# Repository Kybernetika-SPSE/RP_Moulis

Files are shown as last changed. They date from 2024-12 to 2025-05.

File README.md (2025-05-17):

# Modernizace zvukového systému

## 📌 O projektu  
Tento projekt se zaměřuje na modernizaci starého zvukového systému.

## 🛠 Použité technologie  
- **Raspberry Pi Zero 2 W** – hlavní řídicí jednotka  
- **Spotify API** – integrace pro ovládání přehrávání hudby  
- **Raspotify** – umožňuje zařízení fungovat jako Spotify Connect zařízení  
- **Bluetooth Audio** – pro přímé připojení mobilního telefonu  
- **Pulseaudio** – správa zvuku  
- **Spotipy** – Python knihovna pro práci se Spotify  

## ✨ Funkce  
- Přehrávání hudby ze Spotify přes Spotify Connect  
- Možnost připojení přes Bluetooth jako externí reproduktor  
- Zobrazení informací o aktuálně přehrávané skladbě na displeji  
- Více možností zvukového výstupu (3.5 mm Jack, Cinch)  

## 📢 Instalace  
1. **PRaspberry Pi Zero 2 W** s operačním systémem Raspberry Pi OS Lite.  
2. **Potřebné balíčky**:
   ```bash
   sudo apt update && sudo apt install -y curl git python3-pip pulseaudio bluez-tools

- Konfigurace zvukového výstupu: Do souboru /boot/config.txt se přidají následující řádky:
   ```
   dtparam=audio=on
   gpio=12,13,a5
   audio_pwm_mode=2
   dtoverlay=audremap, pins_12_13

- Instalace Raspotify pro přehrávání Spotify:
   ```
   curl -sL https://dtcooper.github.io/raspotify/install.sh | bash

- Konfigurace Bluetooth pro automatické párování:
   ```
   sudo systemctl enable bluetooth
   sudo systemctl start bluetooth

## 🔧 Možná vylepšení
- Integrace baterie pro plně přenosné využití
- Vylepšení grafického rozhraní na displeji
- Snížení šumu na zvukovém výstupu

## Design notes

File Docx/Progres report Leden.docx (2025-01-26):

# Progres report

Leden 2025

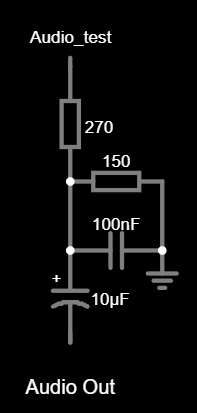
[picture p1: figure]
Obsah obrázku text, snímek obrazovky, Písmo, diagram Popis byl vytvořen automaticky

Moulis Vít

# Audio

Relativně bez problému jsem nastavil audio výstup přes PWM.

Taky jsem na desku nahrál testovací mp3 soubor. V předinstalovaném programu (VLC) jsem ho úspěšně spustil.

Všiml jsem si, že ve výstupu je slyšet šum internetové komunikace, jako připojení internetu přes pevnou linku. Když Raspberry stahuje data nebo mám připojený program na vzdálené ovládání, je to výrazně slyšet, ale při přehrávání není šum rušivý.

Přikládám schéma obvodu. Pro oba kanály jsem udělal jeden takový filtr, aby pomohl vyhladit ostrý zvuk PWM audia.

# RFID

Obrázek 1: Schéma audio filtru

Používám čtečku s čipem RC522 a komunikační frekvencí 13.56 Mhz.

Pro RFID čtečku jsem nainstaloval knihovnu mfrc522 a postupně vyzkoušel několik example kódů. U všech jsem narazil na to, že mi čtečka neregistruje čip. Navíc všechny knihovny jsou buď zastaralé nebo pro Arduino. Zvažuji o použití jiné čtečky RFID, která umožňuje jiný komunikační standard než UART.

# Spotify

Na desku jsem nainstaloval následující knihovny a software:

- Librespot – Knihovna pro imitaci funkcí Spotify Connect
- Raspotify – Rozšírení Librespot pro Raspberry Pi
- Spotipy – Knihovna pro komunikaci se Spotify API přes Python
- Webový prohlížeč Puffin

Narazil jsem na problém s Raspotify, kdy program spadl pokaždé, když jsem se pokusil přenést playback na Raspberry, někdy dokonce spadl celý OS. Musel jsem v configu knihovny Librespot změnit výchozí zařízení pro výstup zvuku, aby fungoval s mým audio výstupem, což probém vyřešilo.

Další krok bude autorizace API, aby deska mohla odesílat příkazy na přehrávání. V tom jsem zatím neuspěl. Mám udělanou aplikaci na stránkách Spotify a snažím se získat autorizaci pro zařízení. Nastavil jsem systémové proměnné s přihlašovacími údaji a stáhl light-weight prohlížeč, který dokáže otevírat webovky graficky.

Program z pythonu vezme přihlašovací údaje a udělá request na autorizaci. Ten se po přihlášení přesměruje na jinou adresu, v mém případě localhost:8080. U přesměrované adresy mi vyskočí error-conection_refused. Všechno tohle zpracovává knihovna Spotipy, co jsem se zjistil z dokumentace a návodu na nastavení tak by si knihovna měla vzít data z přesměrované adresy, což se neděje. Nezáleží na tom, jestli autorizuji přes uživatelské jméno a heslo přímo na raspberry nebo url překopíruju na počítač, tam se přihlásím a vrátím přesměrovanou adresu zpět, výsledek je stejný.

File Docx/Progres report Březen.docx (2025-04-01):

# Progres report

Únor 2025

Moulis Vít

# Hardware

Rozhodl jsem se přidat napájení na usb-C, bohužel jsem byl obehrán breakoutem z Číny a ten poslal 9V přímo do desky. Objednal jsem nové Raspberry Zero a začal jsem resuscitovat sd kartu, ve které se poškodily data. Podařilo se mi zařízení opravit, ale integrace Raspotify nyní nefunguje tak spolehlivě jako předtím, zatím se mi nepodařilo zjistit jestli to je updatem Spotify nebo novou deskou.

Rovněž jsem předělal DAC převodník, který zprostředkovává audio výstup, jelikož pouštěl hodně šumu. Problém jsem nakonec vystopoval na špatně připájené uzemnění cinchů.

# Software

Ze softwarové stránky zařízení funguje, občas se display zasekne nebo přestane fungovat a je potřeba restartovat python skript. Kvůli nutnosti wifi připojení a momentální nespolehlivosti Raspotify knihovny jsem přidal Bluetooth. Zařízení je tak možné používat i offline jako BT reproduktor.

Do python skriptu, který řeší Spotify API požadavky a výstup na display jsem přidal BT mód, kdy zařízení vypisuje:

{logo Bluetooth} Bluetooth

{Jméno aktivního BT zařízení}

# Krabička

Dokončil jsem krabičku pro zařízení, je mnohem robustnější než starý design.

# Implementace

Mírně jsem upravil rozhraní, aby lépe sedělo k reproduktorové věži a zároveň bylo uživatelsky použitelné.

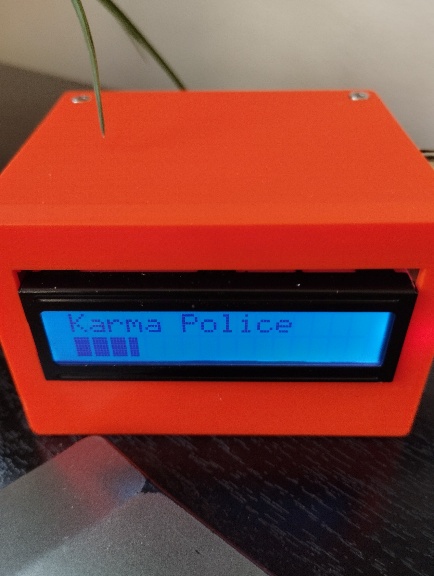
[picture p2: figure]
Obsah obrázku interiér Obsah vygenerovaný umělou inteligencí může být nesprávný.
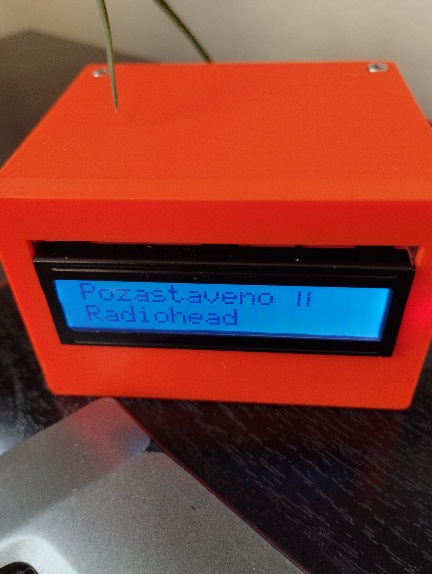
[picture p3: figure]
Obsah obrázku elektronika, interiér Obsah vygenerovaný umělou inteligencí může být nesprávný.
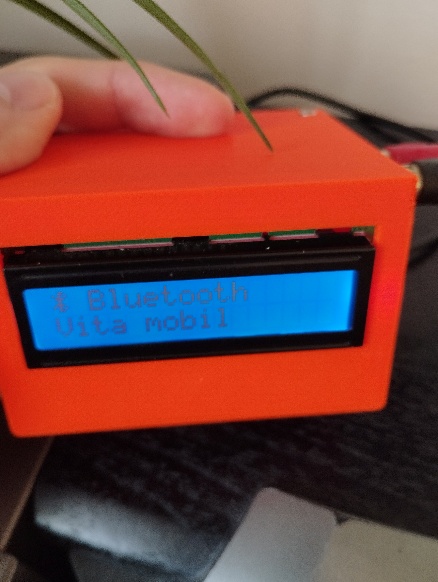
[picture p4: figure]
Obsah obrázku interiér, elektronika Obsah vygenerovaný umělou inteligencí může být nesprávný.

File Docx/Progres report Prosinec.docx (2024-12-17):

# Progress report k 20.12.2024

Prošel jsem internet pro inspiraci. Našel jsem několik podobných projektů a vyvodil jsem, že nejlepší deska pro mě bude Raspberry Pi Zero. Až deska dorazí, dalším krokem bude seznámit se s fungovaním raspberry a také budu muset sestrojit shield na audio výstup + nějaký UI.

O dalším postupu se rozhodnu, až zjistím co je reálně možné s deskou dělat. Podle toho buď přidám display, nebo se ponořím do implementace RFID čtečky. S ní by se dal imitovat vzhled walkmana s kazetkami s RFID čipem, které by při naskenování spustili určitou skladbu nebo album ze Spotify.

Zatím jsem nikde nenašel, že by nějak šlo stahovat skladby ze Spotify kvůli jejich ochraně proti pirátství. Takže nejspíš bude zařízení fungovat pouze s připojením k internetu. Tím pádem docela odpadá smysl dělat zařízení kapesní/přenosné. Zatím nebudu měnit cíl mé práce, rozhodnu se až si vyzkouším, co je možné s deskou dělat.

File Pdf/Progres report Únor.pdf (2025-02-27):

# Progresreport

Únor 2025

Moulis Vít

## Hardware

Mírně jsem přehodnotil, co od zařízení očekávám, zčásti kvůli technickým limitacím.

RFID čtečku, kterou jsem chtěl do zařízení zahrnout, jsem se rozhodl vyřadit. Nepodařilo se mi najít, jak čtečku rozběhnout s Raspberry Pi. Knihovny pro mojí RFID čtečku (mfrc522) buď nejsou pro python nebo nepodporující UART, a jiný standart moje čtečka nepodporuje.

Přidal jsem k zařízení displej, a to LCD1602 s I2C shieldem, který se k životu probral až podezřele snadno. Na display vypisuji informace o playbacku.

STATUS
ZAŘÍZENÍ

NEPŘIPOJENÝ
ÚČET

PŘI PŘIPOJENÍ HUDBA SE
PŘEHRÁVÁ

HUDBA JE
POZASTAVENA
ZPRÁVA NA
PRVNÍM ŘÁDKU
Chyba pri init | Prihlasen jako: | {Název skladby} | Pozastaveno *

ZPRÁVA NA
DRUHÉM ŘÁDKU
Pripojte ucet | {Přihlášený uživatel} | {Interpret} | {Přihlášený uživatel}

*Zde se tiskne vlastní znak, takový ty dvě čárky.

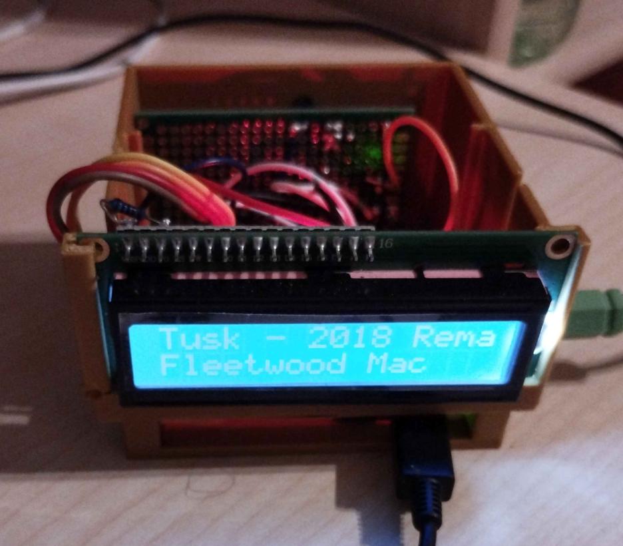
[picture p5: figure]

## Software

Podařilo se mi provést autorizaci zařízení. Knihovna spotipy, přes kterou ovládám spotify playback, má funkci, která automaticky řeší autorizaci tokenů. Pokud to v paměti najde token, tak se autorizuje, pokud ne, pošle web request a získá autorizační kód, se kterým už si poradí. Tento request je potřeba provést pouze jednou, ale právě tady byl problém. Pi Zero 2 W nemá dost RAM na spuštění prohlížeče. Nakonec jsem dokázal obejít prohlížeč tak, že jsem do VS Code nainstaloval rozšíření pro SSH a přes to jsem spustil můj kód v pythonu. Prohlížeč se mi otevřel v počítači a výsledný token se úspěšně vrátil do zařízení.

Zaměřil jsem se na kód v pythonu. Když se spustí, provede se autorizace a pak kód spadne do smyčky, kde dělá API požadavky a bere si údaje o přehrávání. Musel jsem zahrnout i nějaký error handeling, protože pokud není připojen účet, kód má velkou chuť crashovat.

Automatické spuštění přes Crontab. S mírnými obtížemi jsem přidal shell script, který při bootu spustí program. Navíc se každou hodinu provede git pull a jednou denně se zkusí updatovat balíčky.

## Krabička

Udělal jsem pro zařízení krabičku. Zatím jenom prototyp, aby to drželo pohromadě, pořádnou krabičku chci dělat až v březnu.

## Implementace

Mám doma starou Hi-Fi věž, kterou roky nikdo nepoužíval, protože se do ní špatně pouští hudba. Udělal jsem si jack-cinch adaptér a připojil k ní zařízení, a tím jsem tak věži dal druhou šanci.

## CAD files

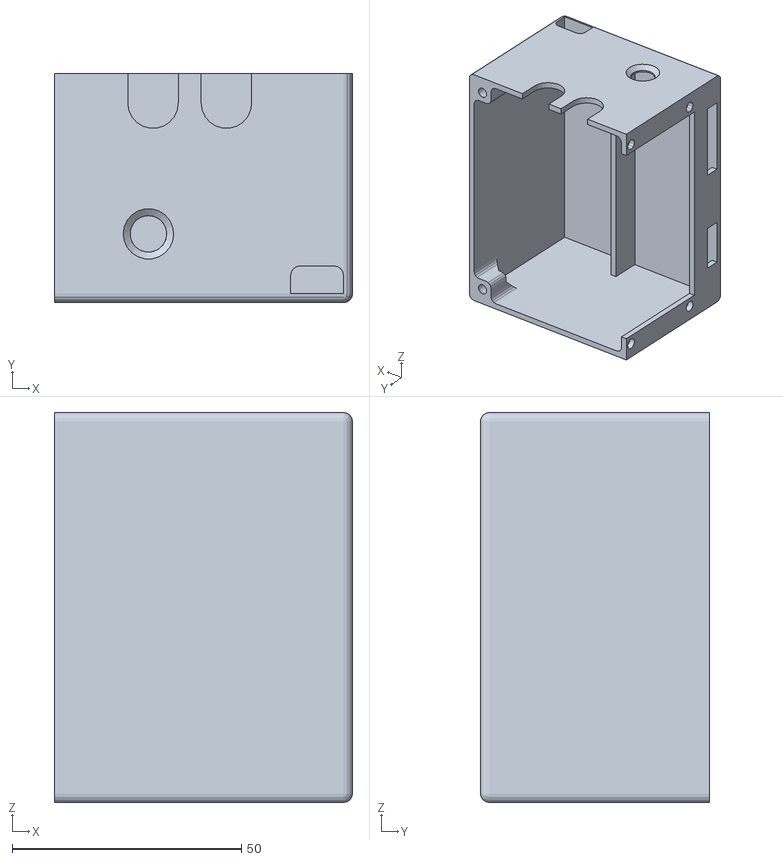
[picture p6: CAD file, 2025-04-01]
Stl/RP.stl
65.0 x 50.0 x 85.0

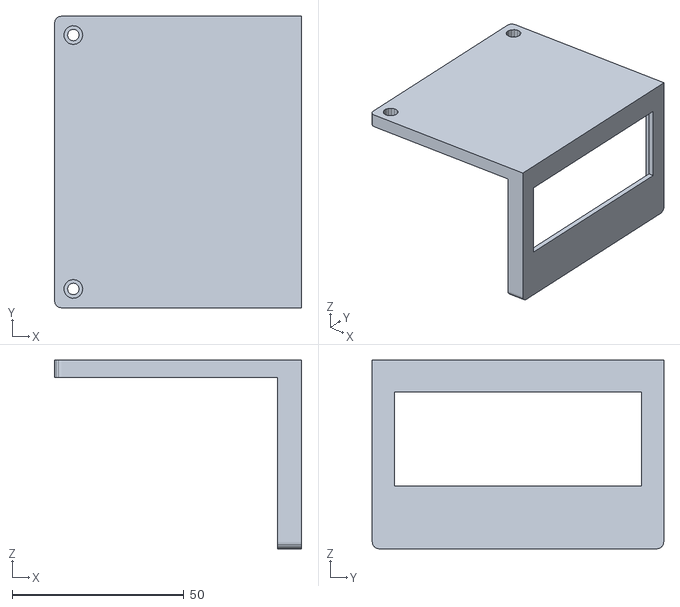
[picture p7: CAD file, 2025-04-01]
Stl/RP_Viko.stl
72.0 x 85.0 x 55.0

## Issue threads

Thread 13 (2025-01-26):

Autorizace tokenů Spotify

RttRng, 2025-01-26:
Mám udělanou aplikaci na stránkách Spotify a snažím se získat autorizaci pro zařízení.
Program v pythonu vezme přihlašovací údaje a udělá request na autorizaci. Ten se po přihlášení
přesměruje na jinou adresu, v mém případě localhost:8080. U přesměrované adresy mi vyskočí error-conection_refused.

Autorizaci zpracovává knihovna Spotipy.
Co jsem se zjistil z dokumentace a návodů na podobných projektů z youtube a githubu, tak by si knihovna měla vzít data z přesměrované adresy, což se neděje.
Nezáleží na tom, jestli autorizuji přes uživatelské jméno a heslo přímo na raspberry, pomocí light-weight prohlížeče, který jsem pro tyto účely nainstaloval, nebo url překopíruju na počítač a tam se přihlásím a vrátím přesměrovanou adresu zpět, výsledek je stejný.
V Spotify aplikaci na jejich webu se dá nastavit redirect adresa podle které se pak autorizace dokončí na zařízení, je dost možný že problém bude někde v tom. Zkoušel jsem tři různé adresy a navíc jsem raději zkusil přidat lomítka, kdyby to třeba mělo vliv. Nemělo.

- http://localhost:8080
- http://localhost:8888/callback
- http://127.0.0.1

Dokumentace knihovny Spotipy: https://spotipy.readthedocs.io/en/2.25.0
Testovací kód v pythonu je Code/spotifyTest.py, přiložený níže pod screenshotem
Dokumentace Spotify API: https://developer.spotify.com/documentation/web-api/tutorials/code-flow

Kód ještě potřebuje k autorizaci client id a client secret z aplikace na spotify development webu, ty si knihovna Spotipy bere z environment variables, což je i bezpečnější. Sice to docela blbne ale dá se to konzistentně uvést do provozu. Rovněž redirect url je napsána jako environment variable, ale pokud funguje client id tak by mělo i tohle.

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

```
import spotipy
from spotipy.oauth2 import SpotifyOAuth
from time import sleep

DEVICE_ID = "35ccd4ae2cab8870610afd219d13b41e84688587"
# Spotify Authentication
sp = spotipy.Spotify(auth_manager=SpotifyOAuth(scope="user-read-playback-state,user-modify-playback-state"))

# Transfer playback to the Raspberry Pi if music is playing on a different device
sp.transfer_playback(device_id=DEVICE_ID, force_play=False)
sp.start_playback(device_id=DEVICE_ID, uris=['spotify:track:2XVQdI3m0giGxNrwUhV3yP'])

```

bublinak, 2025-02-05:
Vezmi s sebou v pátek to Raspberry pokud můžeš. Jestli bys mi ho tam po hodině nechal tak se stav o velké přestávce, zkusím zjistit co je špatně

Closed 2025-04-01.

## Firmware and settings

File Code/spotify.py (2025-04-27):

import spotipy
from spotipy.oauth2 import SpotifyOAuth
from time import sleep
from time import perf_counter
import drivers
from datetime import datetime
import RPi.GPIO as io
import soundcheck as sc
import signal
def handler(signum, frame):
    raise TimeoutError("Funkce trvala příliš dlouho!")
sleep(5)
print("started")
# Deklarace proměnných
client_id='5984261fa2d845b3bcf6463bb1df2c97'
client_secret='9c2280c3c0ae4d9392a8870b90165b91'
redirect_uri='http://localhost:8888/callback'
device_name = 'RPI'
# Inicializace
screen = 17
io.setwarnings(False)
io.setmode(io.BCM)
io.setup(screen, io.OUT)
io.setup(26, io.IN, pull_up_down=io.PUD_UP)
display = drivers.Lcd()
# Definice funkcí
def get_device(name):
    # Získej id zařízení
    device = sp.devices()['devices']
    out = ""
    for i in range(0,len(device)):
        if(device[i]['name']==name):
            out = device[i]['id']
    return out
def long_string_both(display, hraje='', interpret='', play=True, num_cols=16): # řeší vypisování údajů na display
    global refresh
    global tic
    global toc
    global new_user
    global was_playing
    if play != was_playing:
        was_playing = play
        refresh = True
    # zjisti posun textu
    if refresh == True:
        refresh = False
        print("refresh")
        tic = perf_counter()
    toc = perf_counter()
    deltaT = toc-tic
    # zjisti progres písničky v %
    progress = min(int(100*sp.current_playback()["progress_ms"])/sp.current_playback()["item"]["duration_ms"],96)
    for j in range(0,16):
                if j >= len(hraje):
                    hraje = hraje+" "
                if j >= len(interpret):
                    interpret = interpret+" "
    
    i = int(deltaT)
    if play:
        if(len(hraje) > num_cols):
            if(i*4<len(hraje)-num_cols):
                display.lcd_display_string(hraje[i*4:num_cols+i*4+1], 1)
            else:  
                display.lcd_display_string(hraje[len(hraje)-num_cols:len(hraje)], 1)
        else:
            display.lcd_display_string(hraje, 1)
        if(i*4>len(hraje)+4):
            refresh = True
        symbol = ["{0x06}","{0x05}","{0x04}","{0x03}","{0x02}","{0x01}"]
        progress_msg = ""
        progress_index = int(progress/6)
        for j in range(16):
            if(j<progress_index):
                progress_msg = progress_msg+"{0x01}"
            if(j==progress_index):
                progress_msg = progress_msg+symbol[int(progress)-(j*6)]
            if(j>progress_index):
                progress_msg = progress_msg+"{0x06}"
             
        display.lcd_display_extended_string(line=2,string = progress_msg)
                
      
    else:
        display.lcd_display_extended_string(line=1,string="Pozastaveno {0x00}   ")
        if(len(interpret) > num_cols):
            if(i*4<len(interpret)-num_cols):
                display.lcd_display_string(interpret[i*4:num_cols+i*4+1], 2)
            else:  
                display.lcd_display_string(interpret[len(interpret)-num_cols:len(interpret)], 2)
        else:
            display.lcd_display_string(interpret, 2)
        if(i*4>len(interpret)+4):
            refresh = True
    return refresh
def diakritika(string=str): #převod české diakritiky na ascii znaky
    # převeď českou diakritiku na více friendly text
    prevod = [['á','a'],
              ['Á','A'],
              ['č','c'],
              ['Č','C'],
              ['ď','d'],
              ['Ď','D'],
              ['ě','e'],
              ['é','e'],
              ['Ě','E'],
              ['É','E'],
              ['í','i'],
              ['Í','I'],
              ['ň','n'],
              ['Ň','N'],
              ['ó','o'],
              ['Ó','O'],
              ['ř','r'],
              ['Ř','R'],
              ['š','s'],
              ['Š','S'],
              ['ť','t'],
              ['Ť','T'],
              ['ú','u'],
              ['Ú','U'],
              ['ů','u'],
              ['Ů','U'],
              ['ý','y'],
              ['Ý','Y'],
              ['ž','z'],
              ['Ž','Z']]
    for i in range(0,len(prevod)):
        new = ""
        for j in range(0,len(string)):
            if(string[j] == prevod[i][0]):
                new = new+prevod[i][1]
            else:
                new = new+string[j] 
        string = new
    return string
def customchar(): # inicializace vlastních znaků
    global cc
    cc = drivers.CustomCharacters(display)

    # Redefine the default characters:
    # Custom caracter #1. Code {0x00}.
    cc.char_1_data = ["00000",
                    "01001",
                    "01001",
                    "01001",
                    "01001",
                    "01001",
                    "01001",
                    "00000"]

    # Custom caracter #2. Code {0x01}.
    cc.char_2_data = ["11111",
                    "11111",
                    "11111",
                    "11111",
                    "11111",
                    "11111",
                    "11111",
                    "11111"]

    # Custom caracter #3. Code {0x02}.
    cc.char_3_data = ["11110",
                    "11110",
                    "11110",
                    "11110",
                    "11110",
                    "11110",
                    "11110",
                    "11110"]

    # Custom caracter #4. Code {0x03}.
    cc.char_4_data = ["11100",
                    "11100",
                    "11100",
                    "11100",
                    "11100",
                    "11100",
                    "11100",
                    "11100"]

    # Custom caracter #5. Code {0x04}.
    cc.char_5_data = ["11000",
                    "11000",
                    "11000",
                    "11000",
                    "11000",
                    "11000",
                    "11000",
                    "11000"]

    # Custom caracter #6. Code {0x05}.
    cc.char_6_data = ["10000",
                    "10000",
                    "10000",
                    "10000",
                    "10000",
                    "10000",
                    "10000",
                    "10000"]

    # Custom caracter #7. Code {0x06}.
    cc.char_7_data = ["00000",
                    "00000",
                    "00000",
                    "00000",
                    "00000",
                    "00000",
                    "00000",
                    "00000"]

    # Custom caracter #8. Code {0x07}.
    cc.char_8_data = ["00110",
                    "10101",
                    "01110",
                    "00100",
                    "01110",
                    "10101",
                    "00110",
                    "00000"]
    cc.load_custom_characters_data()

    
# Systémové proměné
vol_set = False
refresh = True
playing = True
was_playing = True
tic = 0.0
toc = 0.0
interpret = ""
hraje = ""
new_instance = True
new_user = ""
limited = True
display.lcd_display_string(line=2,string="Started")
io.output(screen, True)
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

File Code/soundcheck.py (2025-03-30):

import subprocess

def check_connected_devices():
    try:
        # Získání seznamu zařízení
        output = subprocess.check_output("bluetoothctl devices", shell=True).decode()
        devices = output.strip().split("\n")
        #print(devices)
        if devices:
            print("Kontroluji připojená Bluetooth zařízení...")
            connected_devices = []
            
            for device in devices:
                # Extrahování adresy zařízení z výstupu (formát: Device XX:XX:XX:XX:XX:XX Name)
                device_address = device.split(" ")[1]
                
                # Kontrola informací o zařízení
                info_output = subprocess.check_output(f"bluetoothctl info {device_address}", shell=True).decode()
                if "Connected: yes" in info_output:
                    # Pokud je zařízení připojeno, přidá jej do seznamu
                    device_name = device.split(" ", 2)[2]  # Název zařízení
                    connected_devices.append(f"{device_name} ({device_address})")
            
            if connected_devices:
                print("Aktuálně připojená Bluetooth zařízení:")
                for connected_device in connected_devices:
                    #print(connected_device)
                    return connected_device
            else:
                print("Žádná zařízení nejsou aktuálně připojena.")
                return False
        else:
            print("Žádná známá zařízení nebyla nalezena.")
            return False
    
    except subprocess.CalledProcessError as e:
        print(f"Chyba při detekci zařízení: {e}")
        return False

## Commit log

2025-01-24 progress leden 1
2025-01-26 Progress report Leden
    Ve složce Pdf
2025-02-11 device id
2025-02-13 Display wrire funct rework
    [spotify.py]
2025-02-13 print type
2025-03-02 Update; screen fix, display msg change, song progress
    [spotify.py, spotifyTest copy.py]
